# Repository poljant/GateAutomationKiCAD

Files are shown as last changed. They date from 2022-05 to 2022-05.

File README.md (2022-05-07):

# GateAutomationKiCAD
Elektronika do GateAutomation

Wersja beta.
Moduł sterowania dwuskrzydłową bramą z oddzielną furtką.
Zasilanie siłowników 12 do 24VDC.
Możliwość zasilania zamka furtki innym napięciem np 12-24VAC.
Jeżeli chcemy zasilić siłowniki wyższym napięciem to należy wymienić U3 na taki, który bedzie przetważał te napięcie na 5VDC 0.8A.
Sterowanie za pomocą pilota 433MHz, wifi 2.4GHz i (lub) modułu HC11 (433MHz).
Gniazda J2 i J3 do podłączenia odbiornika RF 433MHz.
Gniazdo J5 do podłączenia nadajnika RF 433MHz.
Gniazdo J7 do podłączenia układu komunikacji na 433MHz (HC11 lub HC12).
Siłowniki i zamek furtki zabezpieczone są prze zwarciem.
Program do tego układu jest w trakcie tworzenia i testów na repozytorum GateAutomation.
Dalsze informacje będą uzupełniane w trakcie tworzenia i testów.

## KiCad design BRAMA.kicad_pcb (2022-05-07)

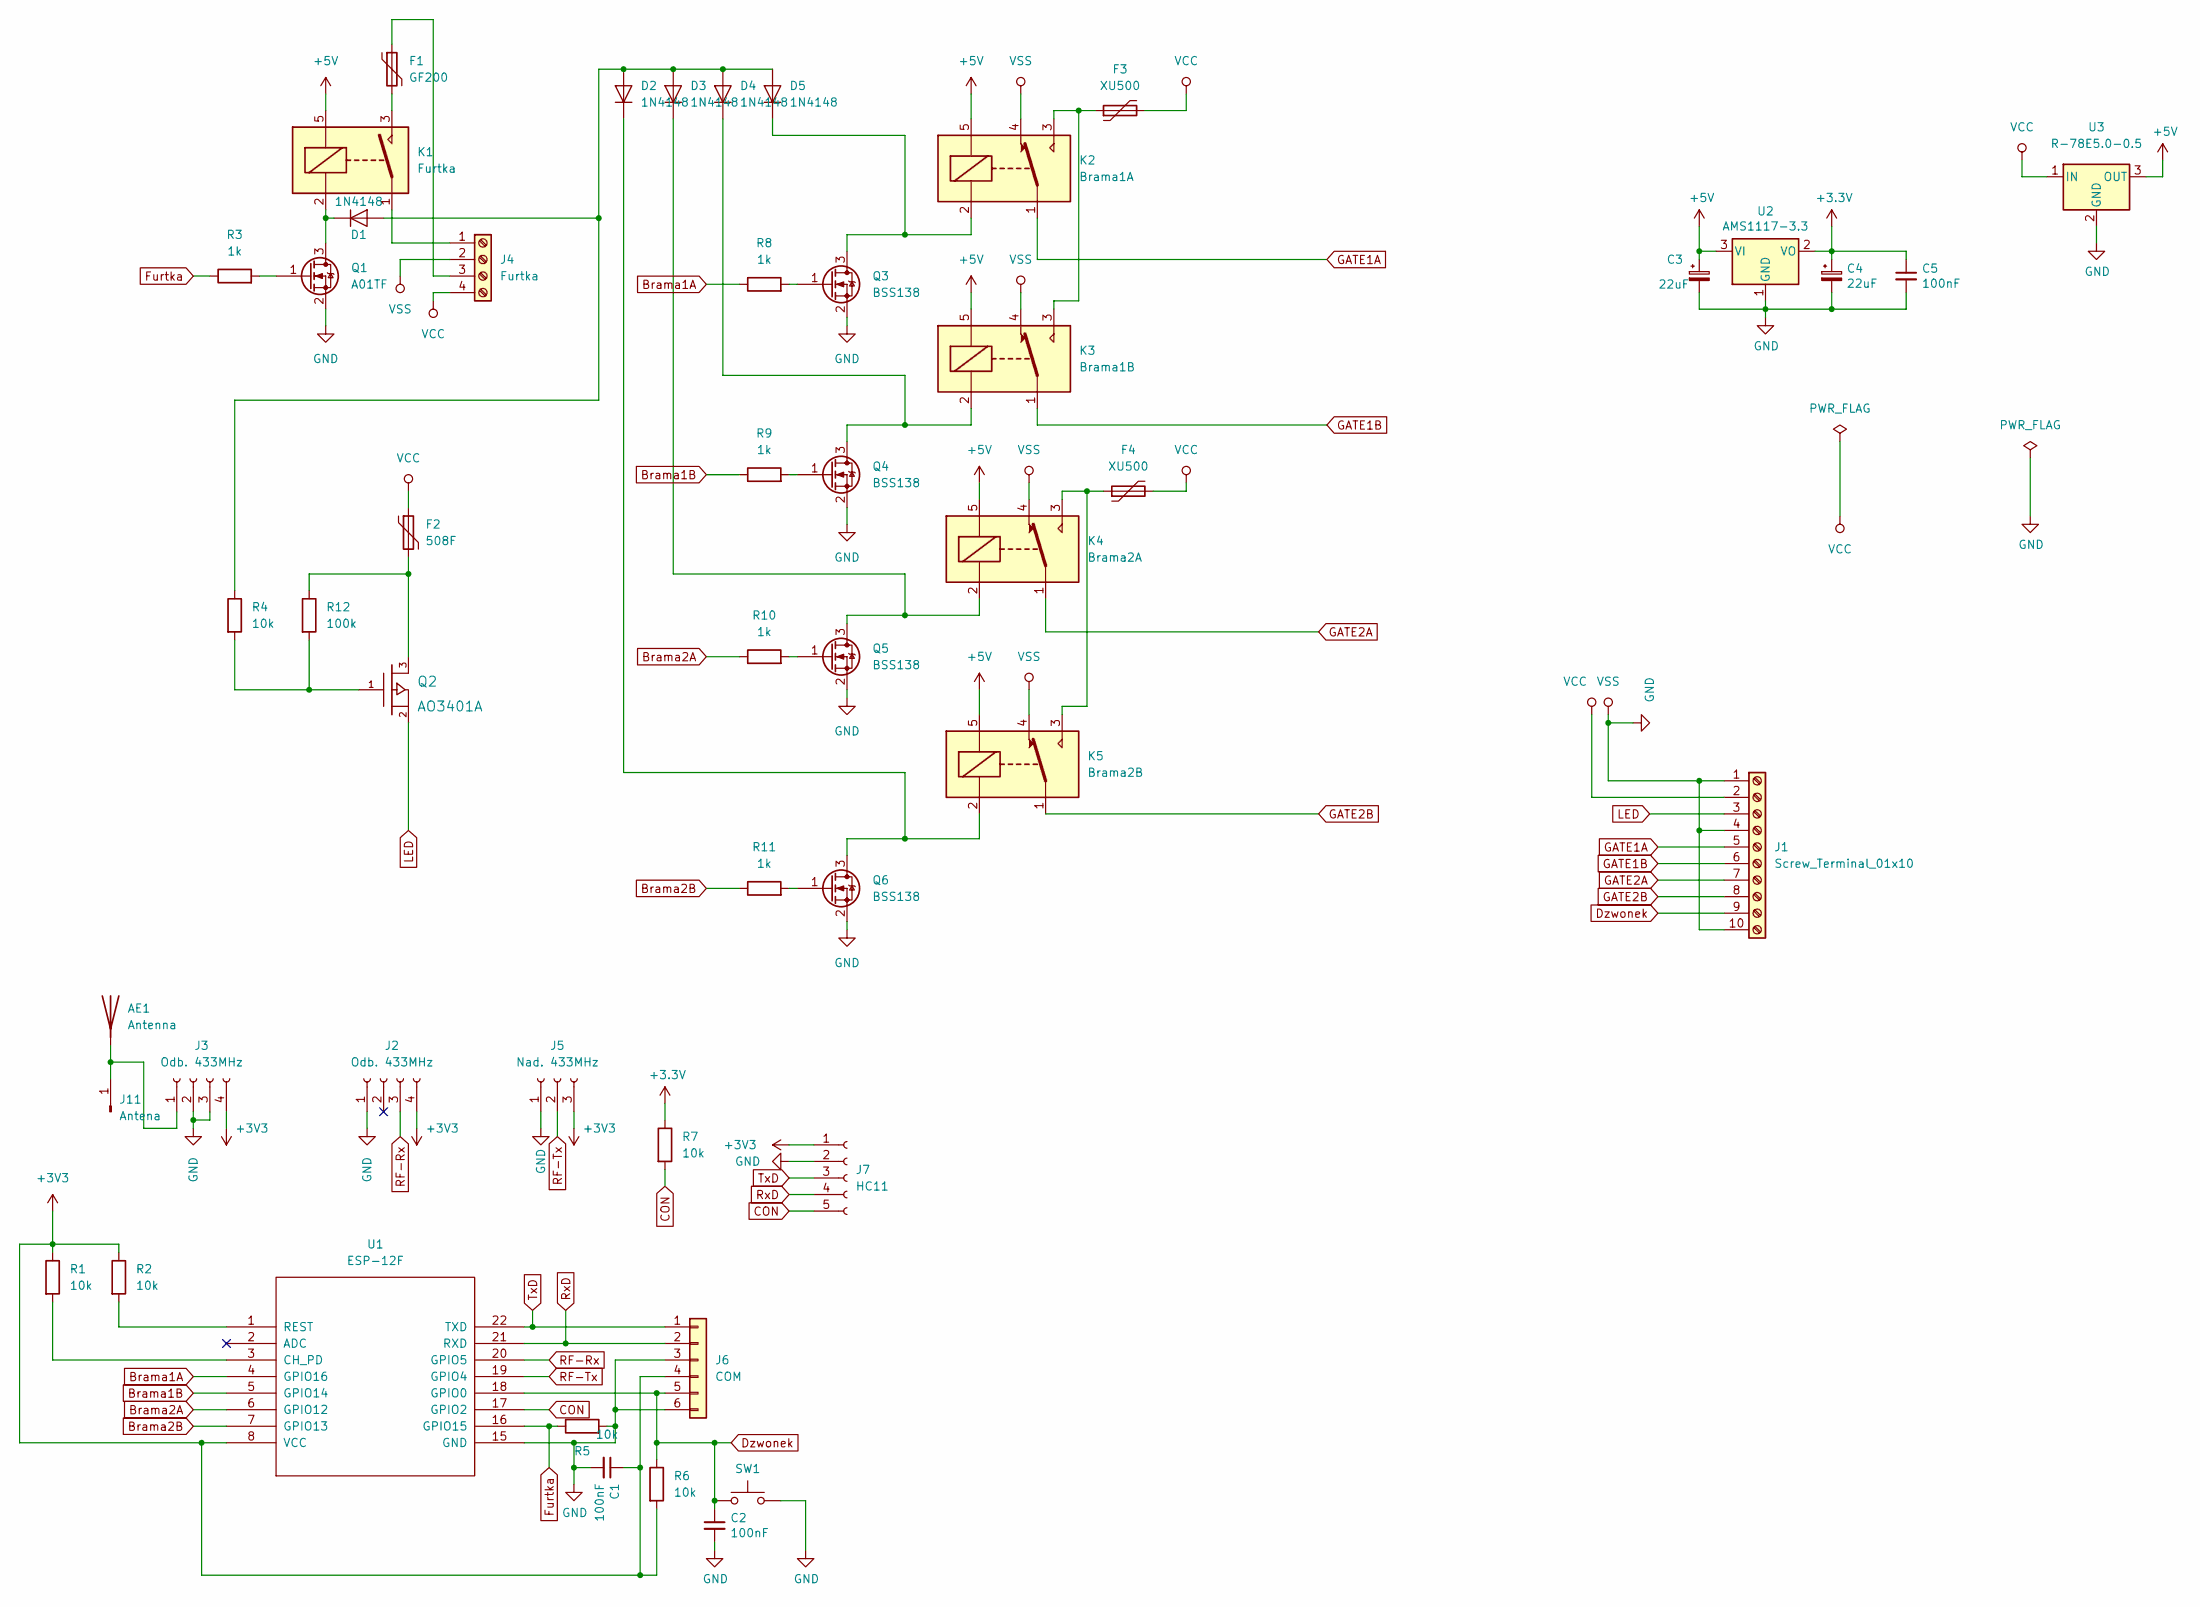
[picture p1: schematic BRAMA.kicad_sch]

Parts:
AE1: Antenna
C1, C2, C5: 100nF; C_1206_3216Metric_Pad1.42x1.75mm_HandSolder
C3, C4: 22uF; CP_Elec_5x4.5
D1, D2, D3, D4, D5: 1N4148; D_SOD-123
F1: GF200; R_Axial_DIN0204_L3.6mm_D1.6mm_P5.08mm_Horizontal
F2: 508F; R_1812_4532Metric_Pad1.30x3.40mm_HandSolder
F3, F4: XU500; R_Axial_DIN0207_L6.3mm_D2.5mm_P10.16mm_Horizontal
J1: Screw_Terminal_01x10; TerminalBlock_Phoenix_MKDS-1,5-10-5.08_1x10_P5.08mm_Horizon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
J2, J3: Odb. 433MHz; PinSocket_1x04_P2.54mm_Vertical
J4: Furtka; TerminalBlock_bornier-4_P5.08mm
J5: Nad. 433MHz; PinSocket_1x03_P2.54mm_Vertical
J6: COM; PinSocket_1x06_P2.54mm_Vertical
J7: HC11; PinSocket_1x05_P2.54mm_Vertical
J11: Antena; PinHeader_1x01_P2.54mm_Vertical
K1: Furtka; Relay_SPDT_SANYOU_SRA_Series_Form_C
K2: Brama1A; Relay_SPDT_SANYOU_SRD_Series_Form_C
K3: Brama1B; Relay_SPDT_SANYOU_SRD_Series_Form_C
K4: Brama2A; Relay_SPDT_SANYOU_SRD_Series_Form_C
K5: Brama2B; Relay_SPDT_SANYOU_SRD_Series_Form_C
Q1: A01TF; SOT-23
Q2: AO3401A; SOT-23_Handsoldering
Q3, Q4, Q5, Q6: BSS138; SOT-23
R1, R2, R4, R5, R6, R7: 10k; R_0805_2012Metric_Pad1.15x1.40mm_HandSolder
R3, R8, R9, R10, R11: 1k; R_0805_2012Metric_Pad1.15x1.40mm_HandSolder
R12: 100k; R_0805_2012Metric_Pad1.15x1.40mm_HandSolder
SW1: SW_Push; SW_SPST_EVPBF
U1: ESP-12F; ESP-12E
U2: AMS1117-3.3; SOT-223-3_TabPin2
U3: R-78E5.0-0.5; Converter_DCDC_RECOM_R-78E-0.5_THT

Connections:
+5V: C3.1, K1.5, K2.5, K3.5, K4.5, K5.5, U2.3 (VI), U3.3 (OUT)
Brama1A: R8.1, U1.4 (GPIO16)
Brama1B: R9.1, U1.5 (GPIO14)
Brama2A: R10.1, U1.6 (GPIO12)
Brama2B: R11.1, U1.7 (GPIO13)
CON: J7.5, R7.2, U1.17 (GPIO2)
Dzwonek: C2.1, J1.9, J6.5, R6.1, SW1.1, U1.18 (GPIO0)
Furtka: R3.1, R5.1, U1.16 (GPIO15)
GATE1A: J1.5, K2.1
GATE1B: J1.6, K3.1
GATE2A: J1.7, K4.1
GATE2B: J1.8, K5.1
GND: C1.2, C2.2, C3.2, C4.2, C5.2, J1.1, J1.4, J1.10, J2.1, J3.2, J3.3, J4.2, J5.1, J6.3, J6.6, J7.2, K2.4, K3.4, K4.4, K5.4, Q1.2 (S), Q3.2 (S), Q4.2 (S), Q5.2 (S), Q6.2 (S), R5.2, SW1.2, U1.15 (GND), U2.1 (GND), U3.2 (GND); also elsewhere on the board
LED: J1.3, Q2.2 (S)
unnamed: AE1.1, J3.1, J11.1
unnamed: D1.1 (K), K1.2, Q1.3 (D)
unnamed: D1.2 (A), D2.2 (A), D3.2 (A), D4.2 (A), D5.2 (A), R4.1
unnamed: D2.1 (K), K5.2, Q6.3 (D)
unnamed: D3.1 (K), K4.2, Q5.3 (D)
unnamed: D4.1 (K), K3.2, Q4.3 (D)
unnamed: D5.1 (K), K2.2, Q3.3 (D)
unnamed: F1.1, J4.3
unnamed: F1.2, K1.3
unnamed: F2.2, Q2.3 (D), R12.1
unnamed: F3.1, K2.3, K3.3
unnamed: F4.1, K4.3, K5.3
unnamed: J4.1, K1.1
unnamed: Q1.1 (G), R3.2
unnamed: Q2.1 (G), R4.2, R12.2
unnamed: Q3.1 (G), R8.2
unnamed: Q4.1 (G), R9.2
unnamed: Q5.1 (G), R10.2
unnamed: Q6.1 (G), R11.2
unnamed: R1.2, U1.3 (CH_PD)
unnamed: R2.2, U1.1 (REST)
RF-Rx: J2.3, U1.20 (GPIO5)
RF-Tx: J5.2, U1.19 (GPIO4)
RxD: J6.2, J7.4, U1.21 (RXD)
TxD: J6.1, J7.3, U1.22 (TXD)
VCC: F2.1, F3.2, F4.2, J1.2, J4.4, U3.1 (IN)

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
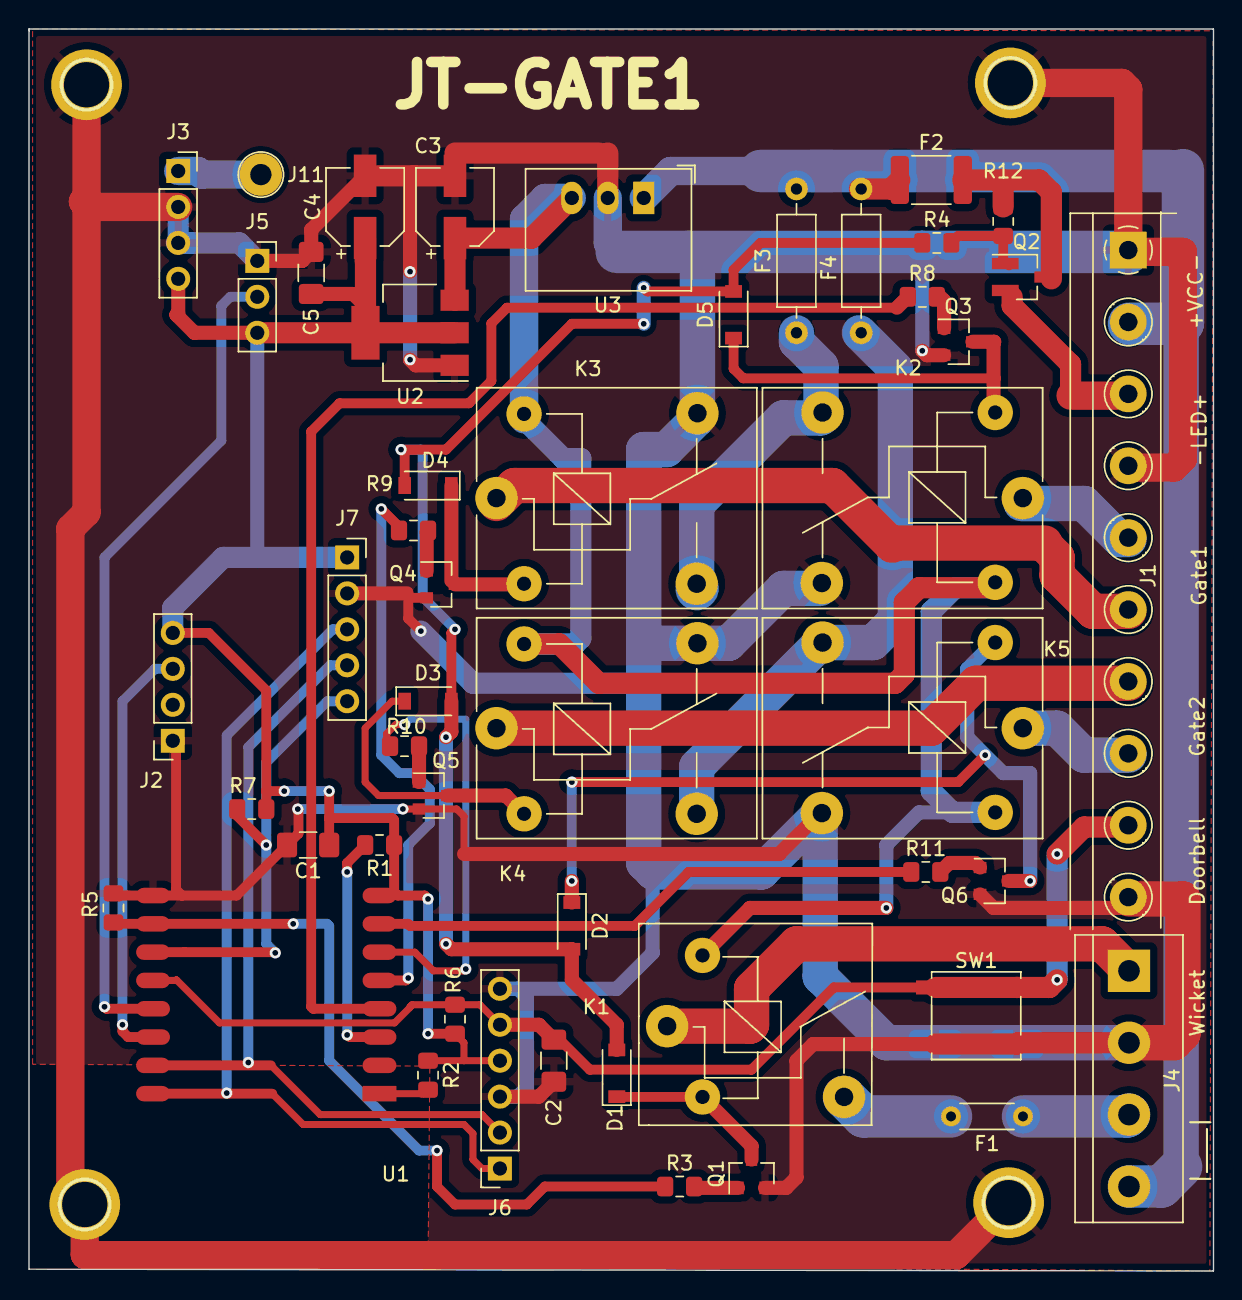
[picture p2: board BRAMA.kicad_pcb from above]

Board: 2 copper layers, 83.7 x 87.8 mm, 53 parts (0 on the bottom side), 41 nets.

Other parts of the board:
pad_3mm, pad_3mm#2, pad_3mm#3, pad_3mm#4: VAL**; pad_3mm

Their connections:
GND: pad_3mm.1, pad_3mm#2.1, pad_3mm#3.1, pad_3mm#4.1; also elsewhere on the board
